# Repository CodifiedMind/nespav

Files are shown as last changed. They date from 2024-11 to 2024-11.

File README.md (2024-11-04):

# nespav
A simple replacement for the NES RF/power module providing composite video and mono audio output. Uses the nifty little Recom R-78K-2.0 switching mode power supply module to simplify the design.

_Composite video amplifier circuit is based on Merlin Shaw's design (https://github.com/ShawMerlin/NES-Power-Module-Redesign)._

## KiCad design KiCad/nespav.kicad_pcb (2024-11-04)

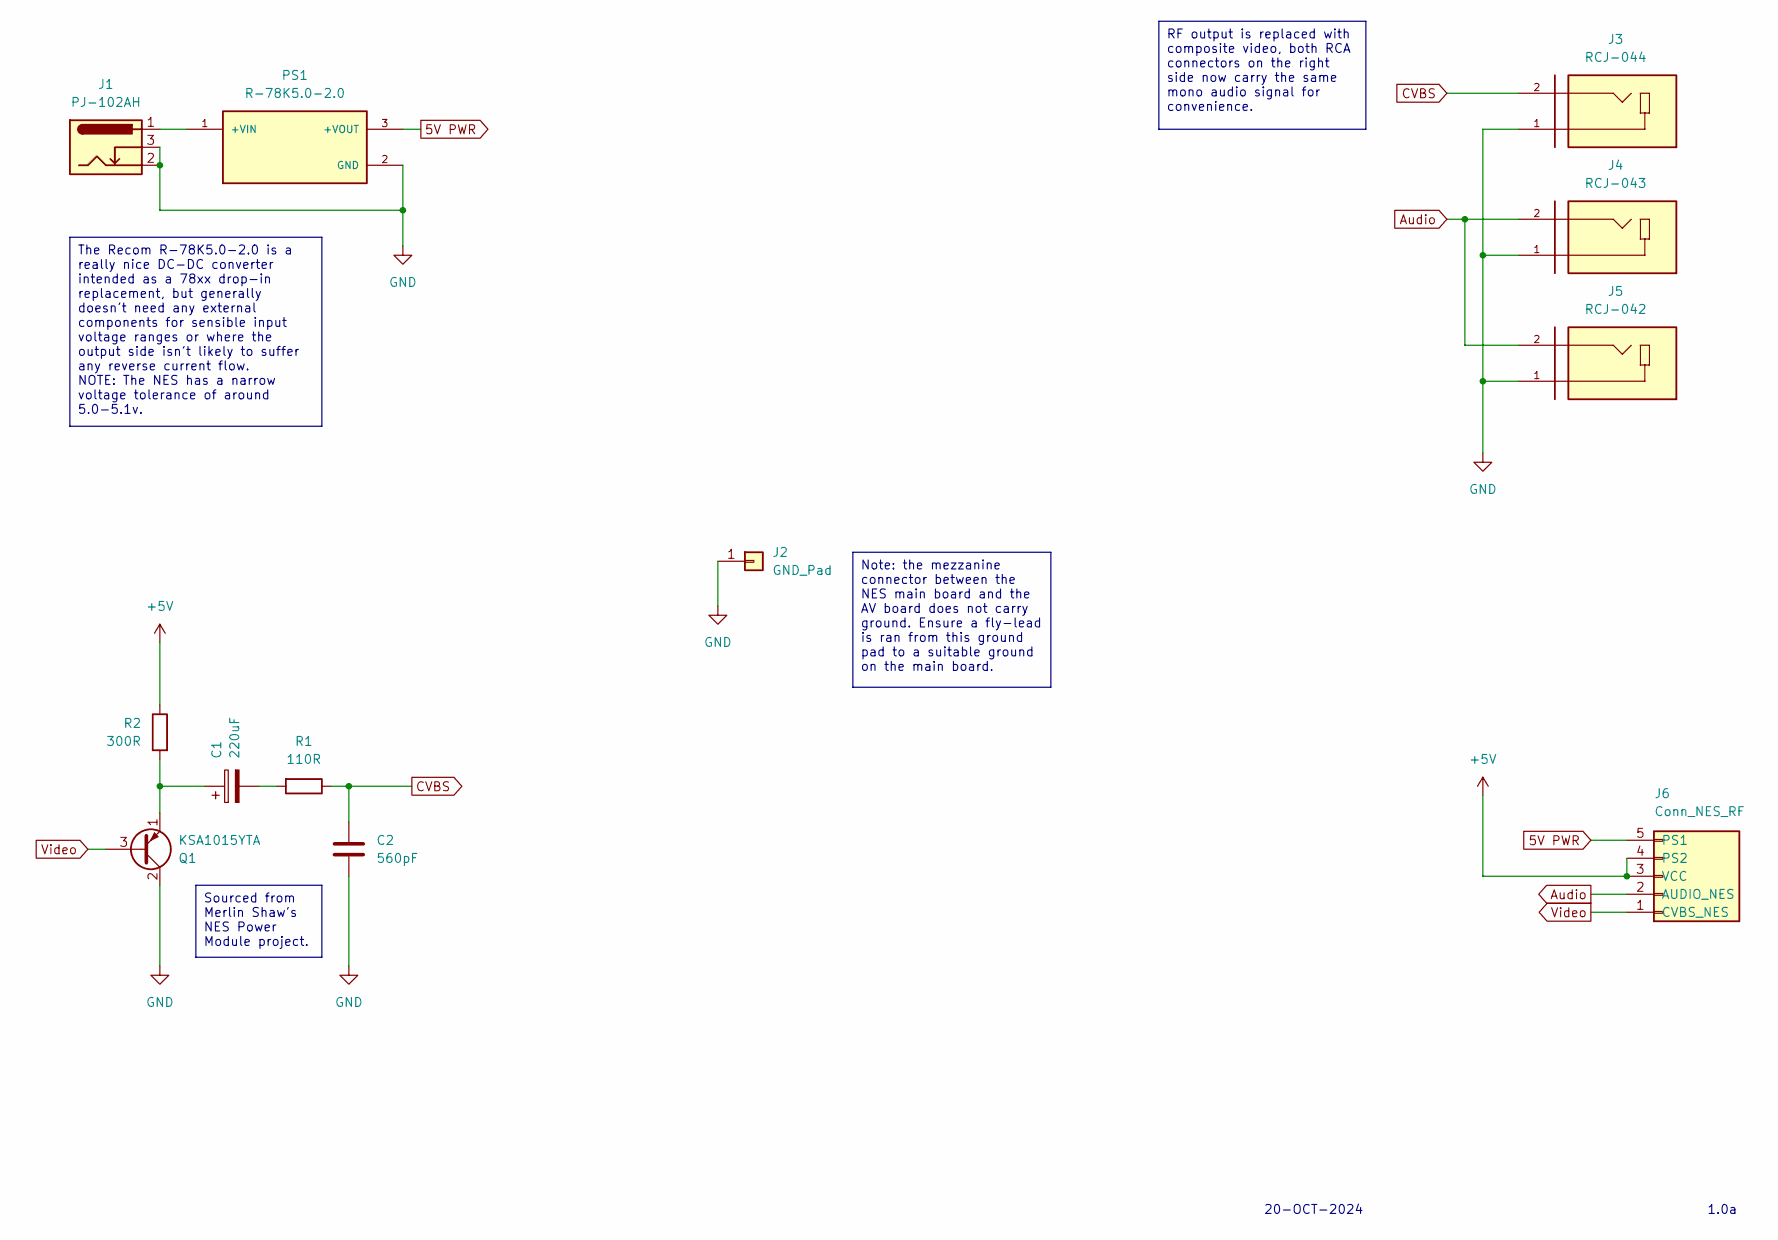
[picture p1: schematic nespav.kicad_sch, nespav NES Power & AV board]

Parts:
C1: 220uF; CP_Radial_D6.3mm_P2.50mm
C2: 560pF; C_Disc_D4.7mm_W2.5mm_P5.00mm
J1: PJ-102AH; BarrelJack_CUI_PJ-102AH_Horizontal
J2: GND_Pad; Pin_D1.3mm_L11.0mm
J3: RCJ-044; CUI_RCJ-044; PARTREV 1.02
J4: RCJ-043; CUI_RCJ-044; PARTREV 1.02
J5: RCJ-042; CUI_RCJ-044; PARTREV 1.02
J6: Conn_NES_RF; RF_CONN_NES
PS1: R-78K5.0-2.0; CONV_R-78K5.0-2.0; PARTREV 0/2023
Q1: KSA1015YTA; TO-92L_Inline_Wide
R1: 110R; R_Axial_DIN0207_L6.3mm_D2.5mm_P10.16mm_Horizontal
R2: 300R; R_Axial_DIN0207_L6.3mm_D2.5mm_P10.16mm_Horizontal

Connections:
5V PWR: J6.5 (PS1), PS1.3 (+VOUT)
+5V: J6.3 (VCC), J6.4 (PS2), R2.1
Audio: J4.2, J5.2, J6.2 (AUDIO_NES)
CVBS: C2.1, J3.2, R1.1
GND: C2.2, J1.2, J1.3, J2.1, J3.1, J4.1, J5.1, PS1.2 (GND), Q1.2 (C)
unnamed: C1.2, R1.2
unnamed: J1.1, PS1.1 (+VIN)
unnamed: C1.1, Q1.1 (E), R2.2
Video: J6.1 (CVBS_NES), Q1.3 (B)

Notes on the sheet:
Note: the mezzanine connector between the NES main board and the AV board does not carry ground. Ensure a fly-lead is ran from this ground pad to a suitable ground on the main board.
RF output is replaced with composite video, both RCA connectors on the right side now carry the same mono audio signal for convenience.
The Recom R-78K5.0-2.0 is a really nice DC-DC converter intended as a 78xx drop-in replacement, but generally doesn't need any external components for sensible input voltage ranges or where the output side isn't likely to suffer any reverse current flow. NOTE: The NES has a narrow voltage tolerance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
Sourced from Merlin Shaw's NES Power Module project.
20-OCT-2024
1.0a

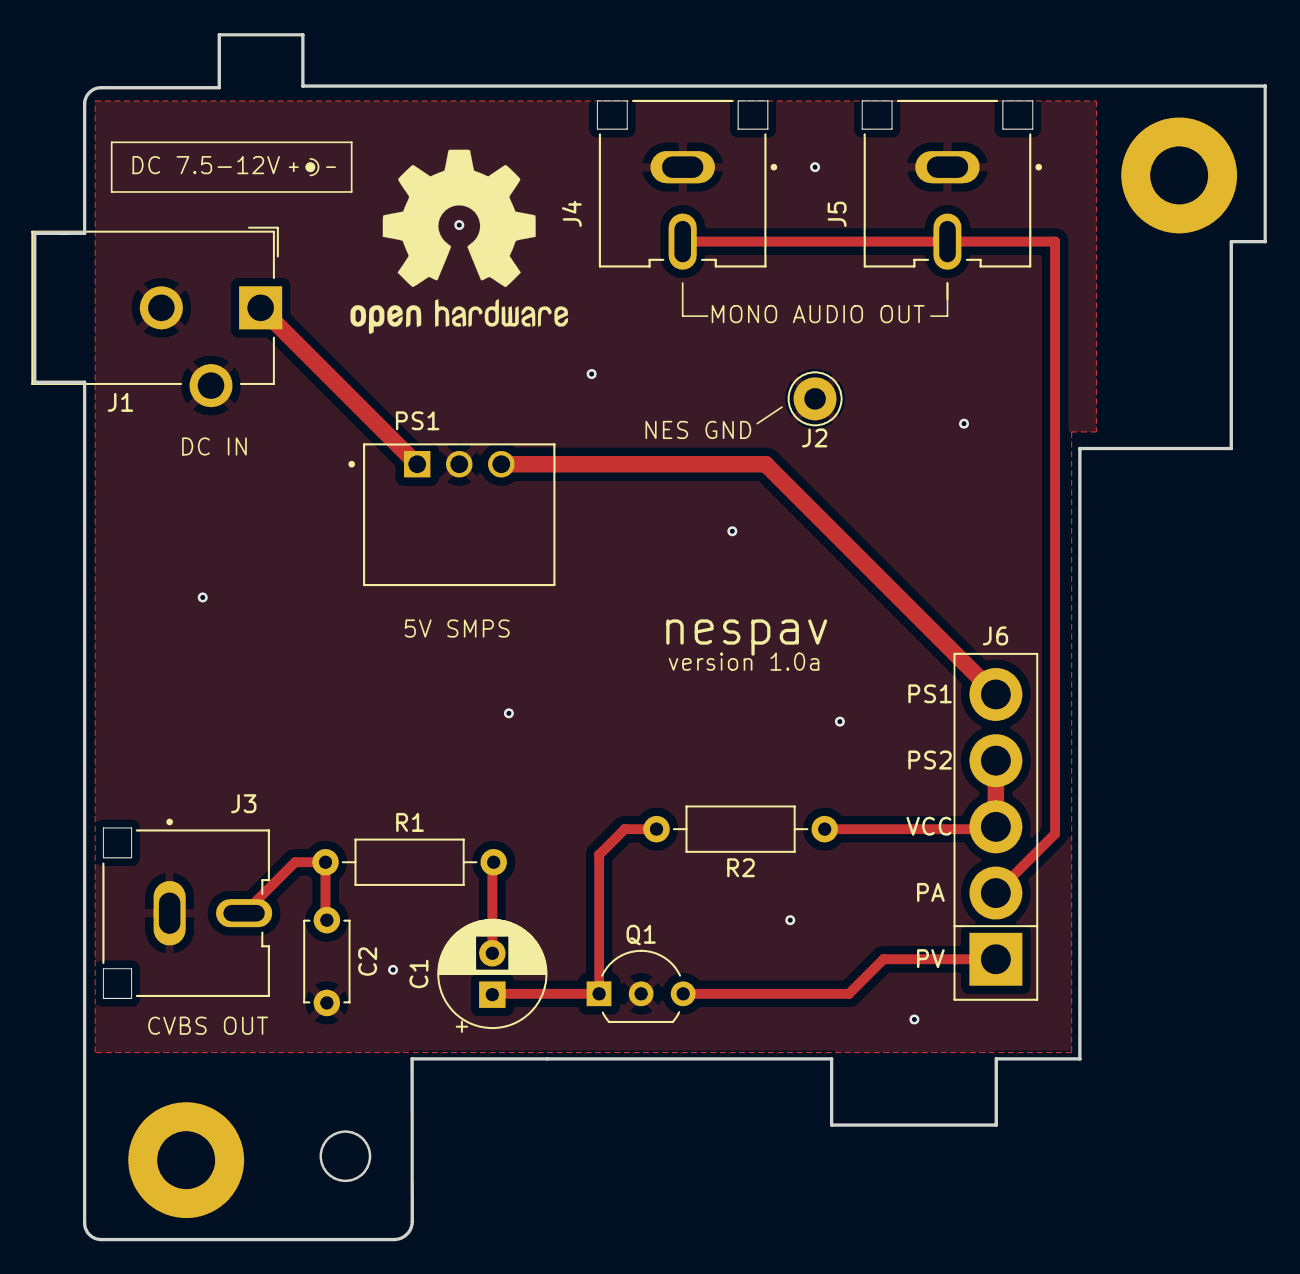
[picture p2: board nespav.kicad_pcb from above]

Board: 2 copper layers, 74.3 x 72.8 mm, 12 parts (0 on the bottom side), 9 nets.
